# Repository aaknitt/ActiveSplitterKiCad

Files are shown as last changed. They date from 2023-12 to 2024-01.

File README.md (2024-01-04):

# ActiveSplitter Multicoupler
Hardware design for an active RF splitter for use with RTL-SDR receivers in the 100 MHz to 1 GHz band.  Not intended to be a piece of precision test equipment, but something inexpensive and "good enough" to use for general radio monitoring and scanning activities in a smaller and more convenient form factor than cable TV splitters or conventional higher end multicouplers.  

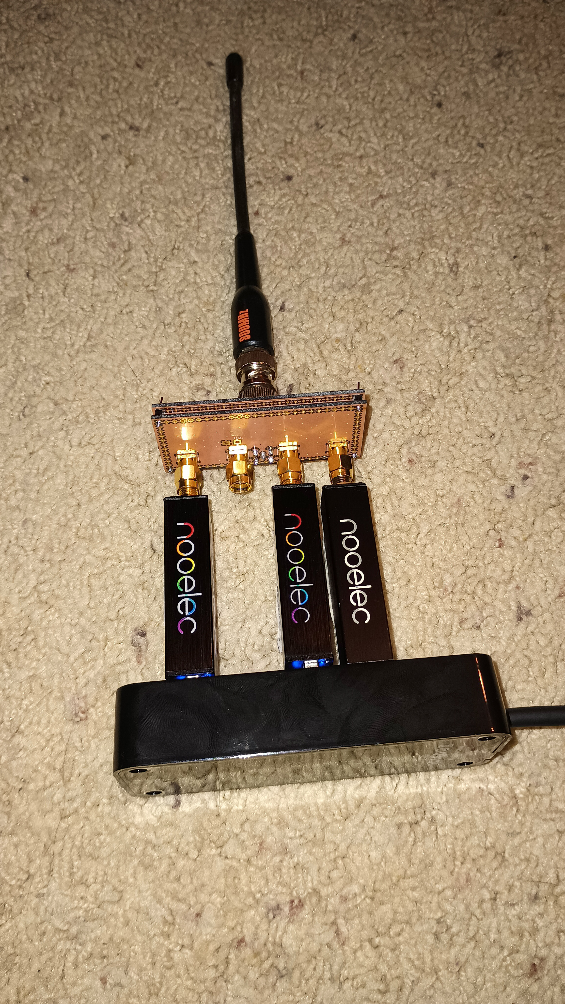
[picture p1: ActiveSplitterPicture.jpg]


Uses amplifier circuit from [this LNA](https://github.com/fabiobaltieri/lna) design.

Design files are in KiCad format.

Estimated cost to build is $40 to $50 in low quantities with U.S. sourced parts.  Could be as low as $10 BOM cost with overseas sourcing and higher quantities.  

## NOTE: I've built one and it seems to function about as intended, but I haven't measured performance using real test equipment yet.  

- Designed to connect four RTL-SDR USB receivers to a single antenna without insertion loss.
- Amplifier circuit provides about 18 dB to 20 dB of gain.  Four way resistive divider results in 12 dB of loss per output, so total is about 6 dB of gain to each port.
- Amplifier is designed to be powered from an SDR providing 3 to 5 volts DC power to the J1 RF output port via a bias tee or from regulated external power.
- Spacing of the output SMA connectors is designed to accomodate plugging the SDR sticks directly into [this](https://www.amazon.com/gp/aw/d/B083XTKV8V) four-port powered USB hub.
- Main board and cover are PCBs.  "Sides" of the box are formed by .1" header pins soldered to each board.  The images show all pins populated, but only every fourth or so is probably need to provide sufficient RF shielding.
- Images below show using one SMA jack for the input and four SMA plugs for outputs connected directly to the RTL-SDR dongles.  However, these can all be substituted for varying SMA genders and orientations (90 degree vs. straight) to accomodate different configurations and cables.
- PCB footprints are included for 50 ohm terminating resistors for any unused outputs.  

## Questions for reviewers:
- Nearly all RF splitter/combiner circuits that I reviewed seemed to be carefuly about maintaining symmetry in the length of all PCB traces in each "branch" of the split.  How important is this, and why?  Is there an "acceptable" amount of assymetery relative to wavelength?  Giving up symmetry would likely allow the PCB to shrink in overall size a bit.  For example, could use a single 4-port splitter instead of two 2-port splits.  That should also increase port to port isolation across adjacent ports.  
- I had originally planned to include a Pi attenuator between the output of the amplifier and the first split to further knock down excessive gain from the amplifier so that insertion loss would cancel out gain.  As it stands, there will probably be about 6 to 8 dB of gain from input to each output.  Is there any reason that could cause problems?  Should I try to add the attenuator back in, even if it makes the overall size larger?
- Will the .1" pin headers create a reasonable Faraday cage instead of a solid housing?
- Is there any advantage or reason to combine R6 with R8  and R5 with R7?
- Should the splitter that starts with R6 be closer to R8 (same with R5/R7)?
- Is the circuit providing DC power to the amplifier (L1, L2, C2) reasonable?
- Should the values of C1 and C3 be changed to support the target range of 100 MHz to 1 GHz?

Assembled View:

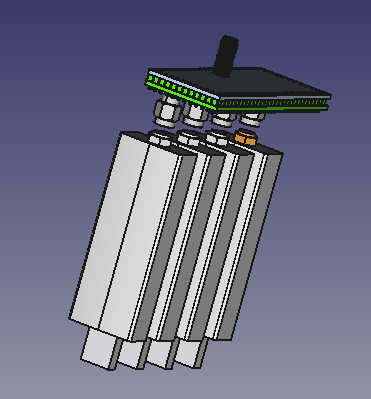
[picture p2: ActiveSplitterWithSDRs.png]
Assembly View


Schematic [PDF](https://github.com/aaknitt/ActiveSplitterKiCad/blob/main/ActiveSplitterSchematic.pdf):
Schematic

Main PCB View 1:

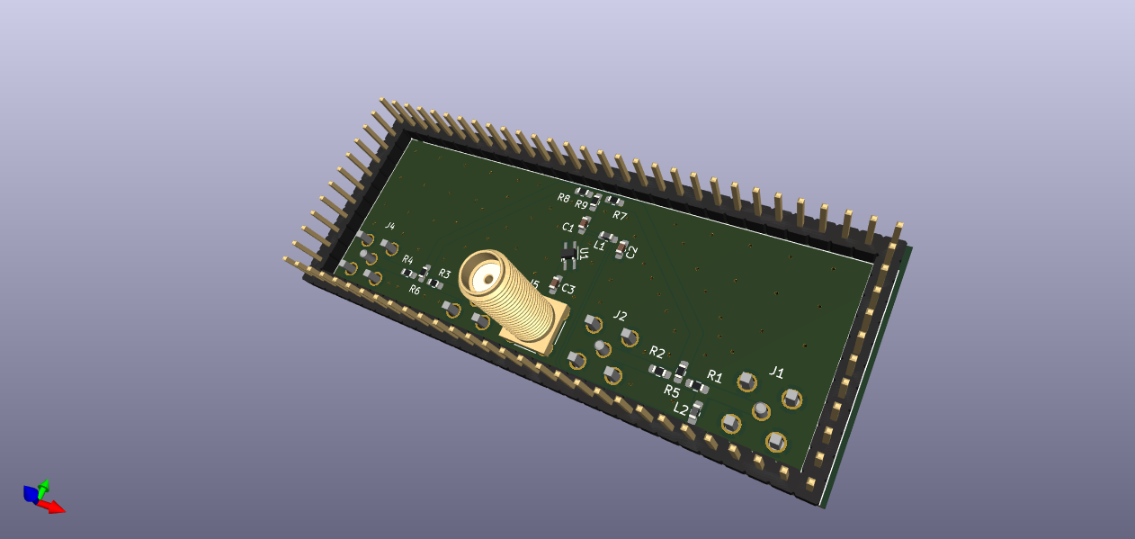
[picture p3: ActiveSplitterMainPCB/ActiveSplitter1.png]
Main PCB View 1


Main PCB View 2:

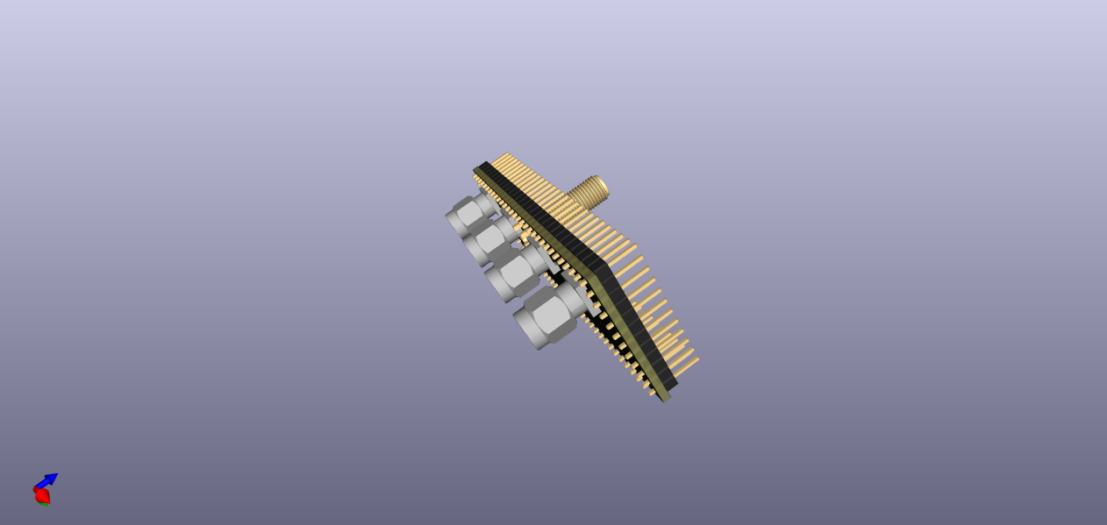
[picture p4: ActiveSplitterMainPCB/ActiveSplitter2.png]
Main PCB View 2


Cover PCB:

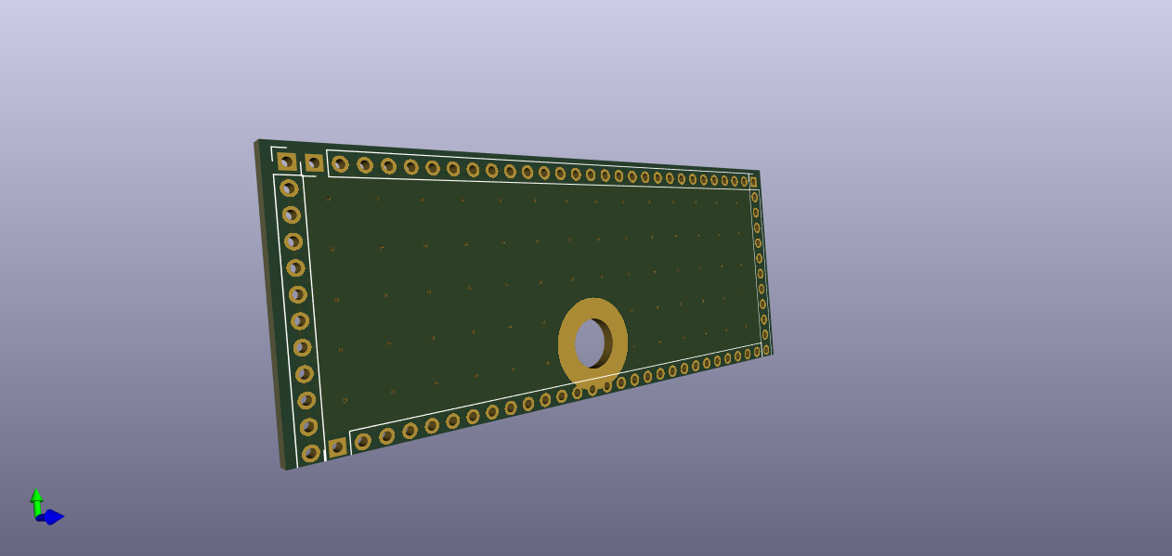
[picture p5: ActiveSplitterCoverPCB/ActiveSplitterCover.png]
Cover PCB


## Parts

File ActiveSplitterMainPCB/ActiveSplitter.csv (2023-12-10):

Source: | C:\Users\andyk\Google Drive\Ham Radio & Scanner\ActiveSplitter\ActiveSplitter\ActiveSplitter.kicad_sch
Date: | 12/9/2023 4:56:37 PM
Tool: | Eeschema 7.0.9
Generator: | C:\Program Files\KiCad\7.0\bin\scripting\plugins/bom_csv_grouped_by_value.py
Component Count: | 24
Collated Components:
Item | Qty | Reference(s) | Value | LibPart | Footprint | Datasheet | DNP
1 | 2 | C1, C3 | 100p | ActiveSplitter-eagle-import:C-EUC0603 | Capacitor_SMD:C_0603_1608Metric_Pad1.08x0.95mm_HandSolder
2 | 1 | C2 | 10n | ActiveSplitter-eagle-import:C-EUC0603 | Capacitor_SMD:C_0603_1608Metric_Pad1.08x0.95mm_HandSolder
3 | 4 | J1, J2, J3, J4 | SMA_EDGE | ActiveSplitter-eagle-import:SMA_EDGE | Connector_Coaxial:SMA_Amphenol_132291_Vertical
4 | 1 | J5 | SMA_EDGE | ActiveSplitter-eagle-import:SMA_EDGE | Connector_Coaxial:SMA_Amphenol_132291-12_Vertical
5 | 2 | J6, J7 | Conn_01x28_Pin | Connector:Conn_01x28_Pin | Connector_PinHeader_2.54mm:PinHeader_1x28_P2.54mm_Vertical | ~
6 | 2 | J8, J9 | Conn_01x12_Pin | Connector:Conn_01x12_Pin | Connector_PinHeader_2.54mm:PinHeader_1x12_P2.54mm_Vertical | ~
7 | 2 | L1, L2 | 200n | ActiveSplitter-eagle-import:INDUCTOR0603 | Inductor_SMD:L_0603_1608Metric_Pad1.05x0.95mm_HandSolder
8 | 9 | R1, R2, R3, R4, R5, R6, R7, R8, R9 | R | Device:R | Resistor_SMD:R_0603_1608Metric_Pad0.98x0.95mm_HandSolder | ~
9 | 1 | U1 | PSA4-5043 | ActiveSplitter-eagle-import:PSA4-5043 | Package_TO_SOT_SMD:SOT-343_SC-70-4_Handsoldering

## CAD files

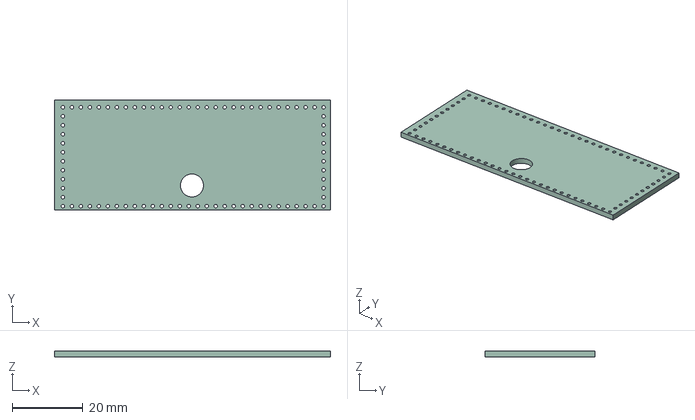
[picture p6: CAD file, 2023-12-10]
ActiveSplitterCoverPCB/ActiveSplitterCover.step
78.0 x 31.0 x 1.60 mm

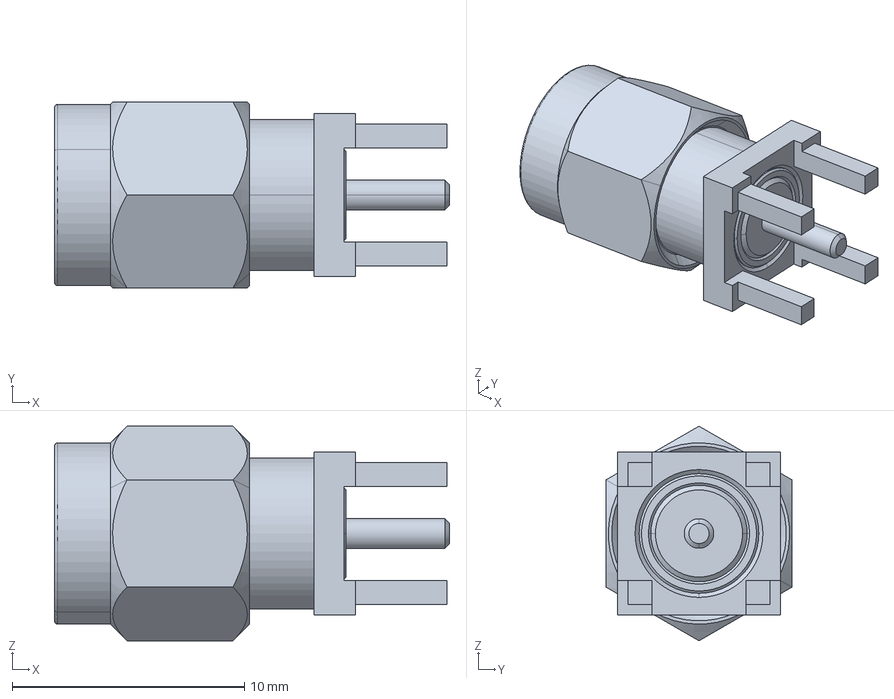
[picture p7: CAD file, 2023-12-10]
ActiveSplitterMainPCB/901-9895-RFX.stp
17.0 x 8.00 x 9.24 mm

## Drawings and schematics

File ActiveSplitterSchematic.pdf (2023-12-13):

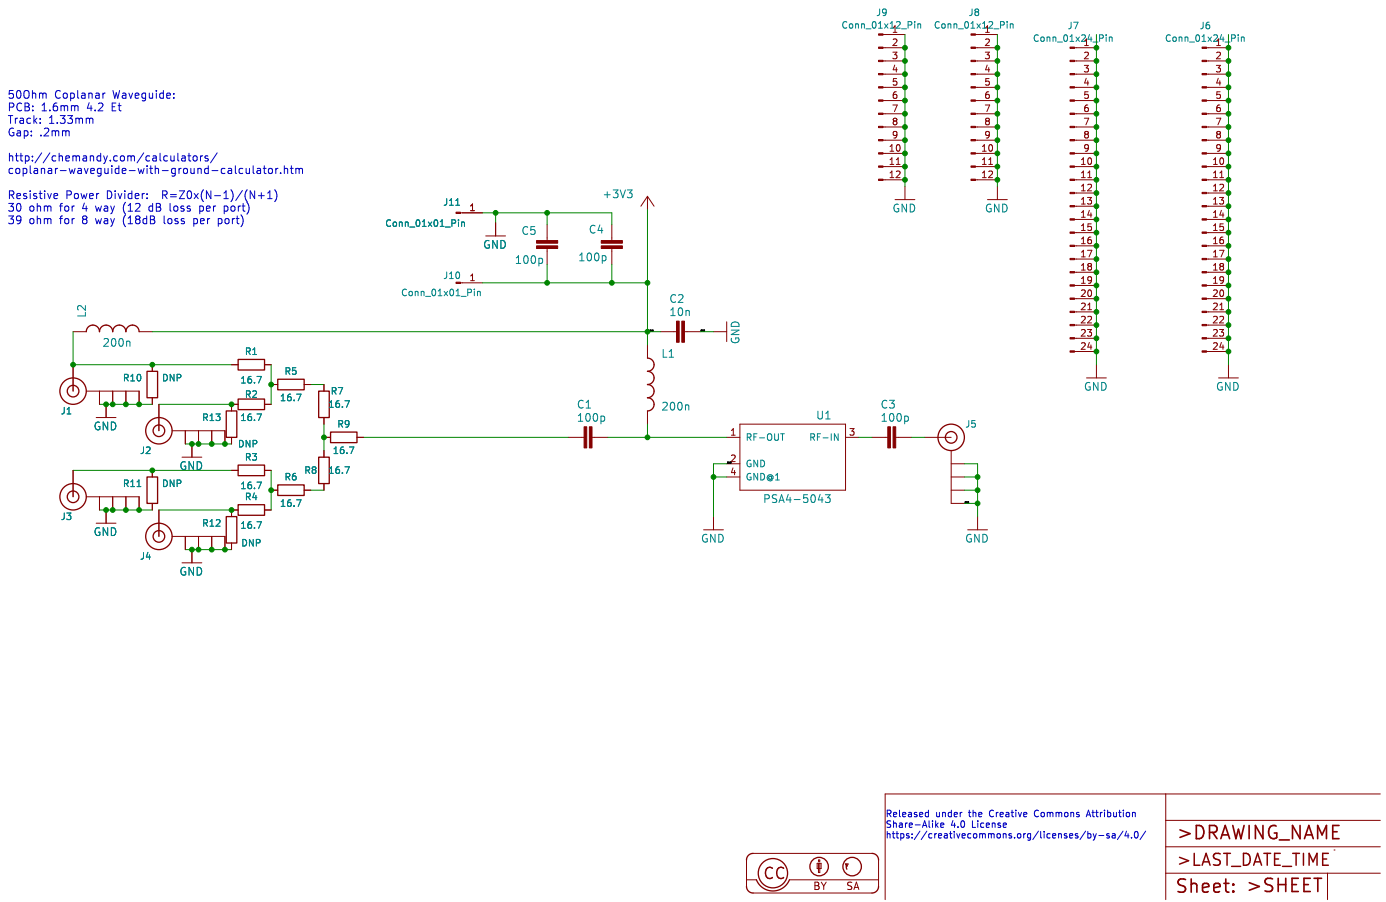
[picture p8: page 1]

http://chemandy.com/calculators/
coplanar-waveguide-with-ground-calculator.htm

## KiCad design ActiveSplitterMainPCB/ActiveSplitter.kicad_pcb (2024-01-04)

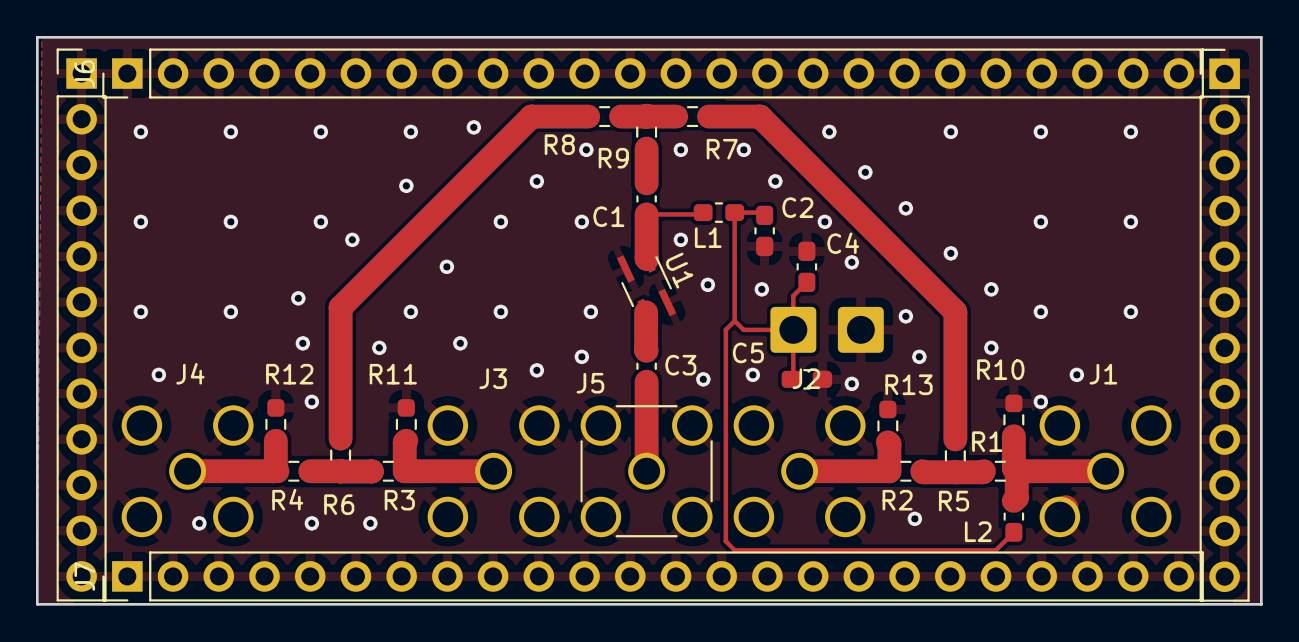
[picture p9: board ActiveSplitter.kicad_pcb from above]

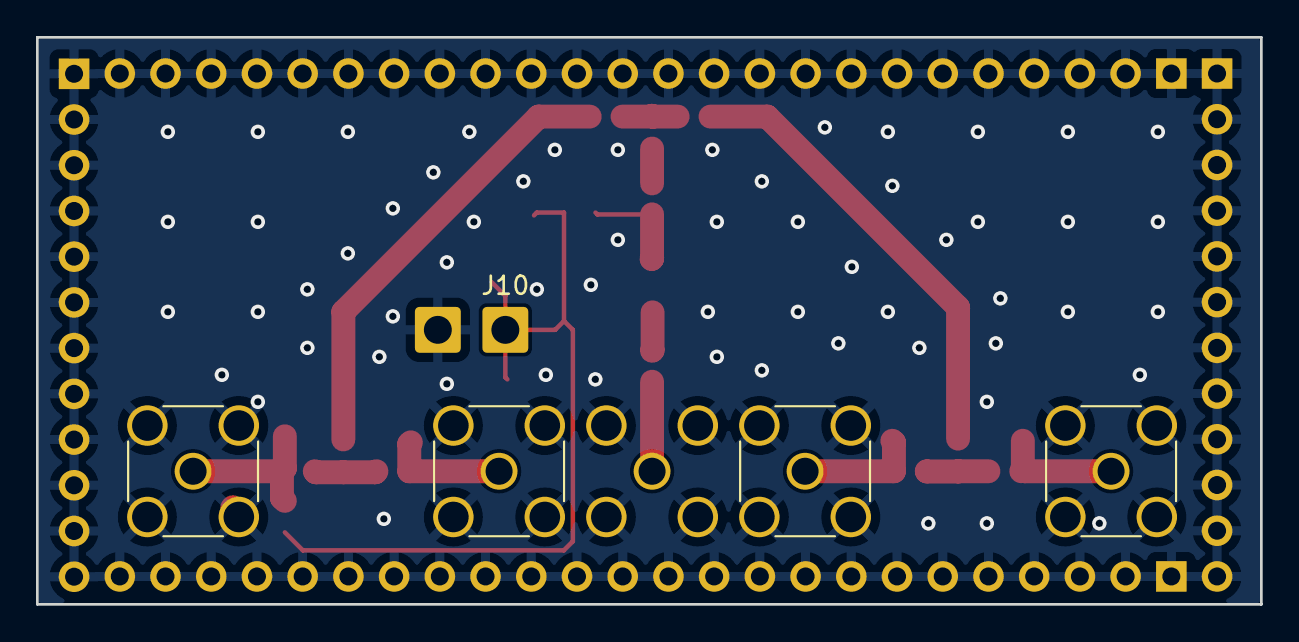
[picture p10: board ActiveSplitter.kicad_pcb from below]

Board: 2 copper layers, 68.0 x 31.5 mm, 32 parts (4 on the bottom side), 15 nets.

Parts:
C1, C3, C4, C5: 100p; C_0603_1608Metric_Pad1.08x0.95mm_HandSolder
C2: 10n; C_0603_1608Metric_Pad1.08x0.95mm_HandSolder
J1, J2, J3, J4: SMA_EDGE; SMA_Amphenol_132291_Vertical
J5: SMA_EDGE; SMA_Amphenol_132291-12_Vertical
J6, J7: Conn_01x24_Pin; PinHeader_1x24_P2.54mm_Vertical
J8, J9: Conn_01x12_Pin; PinHeader_1x12_P2.54mm_Vertical
J10, J11: Conn_01x01_Pin; SolderWire-0.75sqmm_1x01_D1.25mm_OD2.3mm
L1, L2: 200n; L_0603_1608Metric_Pad1.05x0.95mm_HandSolder
R1, R2, R3, R4, R5, R6, R7, R8, R9: 30; R_0603_1608Metric_Pad0.98x0.95mm_HandSolder
R10, R11, R12, R13: DNP; R_0603_1608Metric_Pad0.98x0.95mm_HandSolder
U1: PSA4-5043; SOT-343_SC-70-4_Handsoldering

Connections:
+3V3: C2.1, C4.1, C5.1, J10.1, L1.1, L2.2
GND: C2.2, C4.2, C5.2, J1.2, J2.2, J3.2, J4.2, J5.2, J6.1, J6.2, J6.3, J6.4, J6.5, J6.6, J6.7, J6.8, J6.9, J6.10, J6.11, J6.12, J6.13, J6.14, J6.15, J6.16, J6.17, J6.18, J6.19, J6.20, J6.21, J6.22, J6.23, J6.24, J7.1, J7.2, J7.3, J7.4, J7.5, J7.6, J7.7, J7.8, J7.9, J7.10, J7.11, J7.12, J7.13, J7.14, J7.15, J7.16, J7.17, J7.18, J7.19, J7.20, J7.21, J7.22, J7.23, J7.24, J8.1, J8.2, J8.3, J8.4, J8.5, J8.6, J8.7, J8.8, J8.9, J8.10, J8.11, J8.12, J9.1, J9.2, J9.3, J9.4, J9.5, J9.6, J9.7, J9.8, J9.9, J9.10, J9.11, J9.12, J11.1, R10.1, R11.1, R12.1, R13.1, U1.2 (GND), U1.4 (GND@1)
unnamed: C1.1, R9.1
unnamed: J1.1 (SIGNAL), L2.1, R1.1, R10.2
unnamed: J2.1 (SIGNAL), R2.1, R13.2
unnamed: J3.1 (SIGNAL), R3.1, R11.2
unnamed: J4.1 (SIGNAL), R4.1, R12.2
unnamed: C3.2, J5.1 (SIGNAL)
unnamed: R1.2, R2.2, R5.2
unnamed: R3.2, R4.2, R6.2
unnamed: R5.1, R7.2
unnamed: R6.1, R8.1
unnamed: R7.1, R8.2, R9.2
unnamed: C3.1, U1.3 (RF-IN)
unnamed: C1.2, L1.2, U1.1 (RF-OUT)

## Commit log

2023-12-10 add termination resistors, PDF and SVG outputs for viewing
    [ActiveSplitter.kicad_pcb, ActiveSplitter.kicad_sch]
2023-12-10 add image of FreeCAD assembly with SDRS
2023-12-10 add schematic SVG
2023-12-10 Reduced output SMA spacing to 17mm to match USB hub. Added pad for external 3V supply.
    [ActiveSplitter.kicad_pcb, ActiveSplitter.kicad_sch]
2023-12-10 silkscreen cleanup
    [ActiveSplitter.kicad_pcb]
2023-12-12 fix keepout zones
    [ActiveSplitter.kicad_pcb]
2023-12-13 fix resistor values
    [ActiveSplitter.kicad_sch]
2023-12-13 update size of cover PCB
    [ActiveSplitterCover.kicad_pcb, ActiveSplitterCover.kicad_sch]

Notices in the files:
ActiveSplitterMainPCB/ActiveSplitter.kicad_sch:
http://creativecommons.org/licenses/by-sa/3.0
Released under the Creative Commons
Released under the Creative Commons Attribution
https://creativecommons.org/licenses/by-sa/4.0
